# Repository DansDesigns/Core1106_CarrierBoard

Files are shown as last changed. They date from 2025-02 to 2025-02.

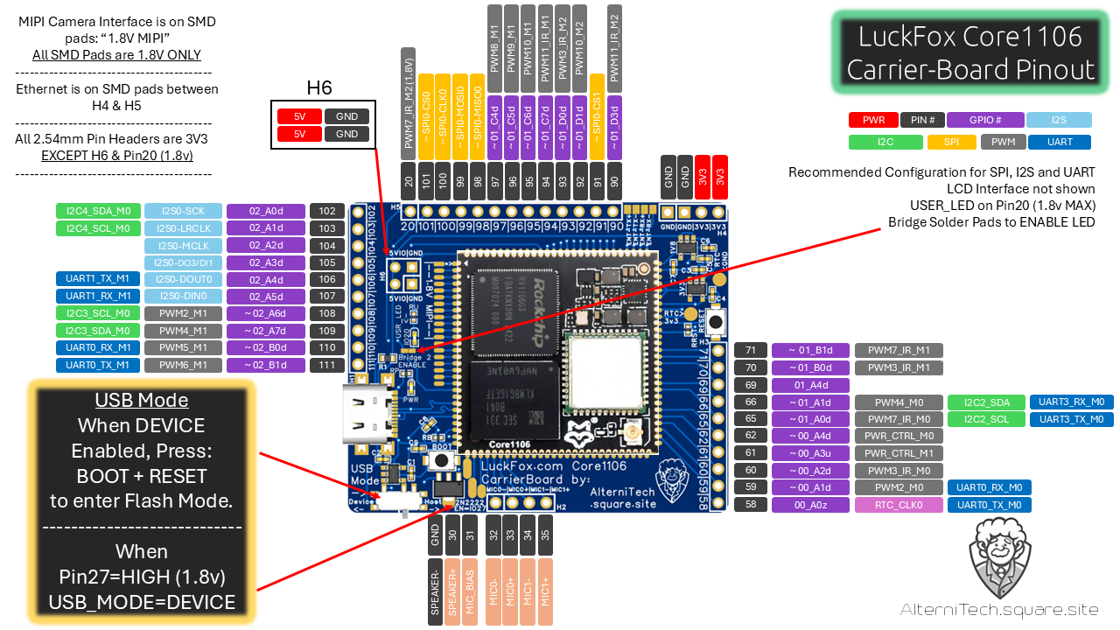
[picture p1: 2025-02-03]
LuckFox_Core1106_EasyRead_Pinout.png

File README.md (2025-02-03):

# Core1106_CarrierBoard
 Carrier Board for LuckFox Core1106 Linux SBC
LuckFox_Core1106_EasyRead_Pinout

## Features:

* All usable GPIO's are connected to 2.54mm Pin Headers (all 3.3v Logic EXCEPT Pin20 (1.8v MAX))
* ALL SMD Pads are 1.8v, EXCEPT for ENET (Ethernet)
* USB-C Programming/USB Host
* USB Mode Switch connects 3.3v & USB_VBUSDET (Enable to enter USB Device Mode, PRESS BOOT + RESET to enter Flash Mode)
* 2N2222 Transistor with ENABLE on Pin27 does same ^^^^^^ (when Pin27 is HIGH (1.8v))
* 5v pins on H6 are directly connected to USB - can be used for In/Out
* 3v3 pins are powered by "3v3" LDO (shared with 3v3SYS) (max 500ma)
* User LED connected to Pin20 (GPIO3_C6d)
	- Connect Solder Pads to ENABLE
*

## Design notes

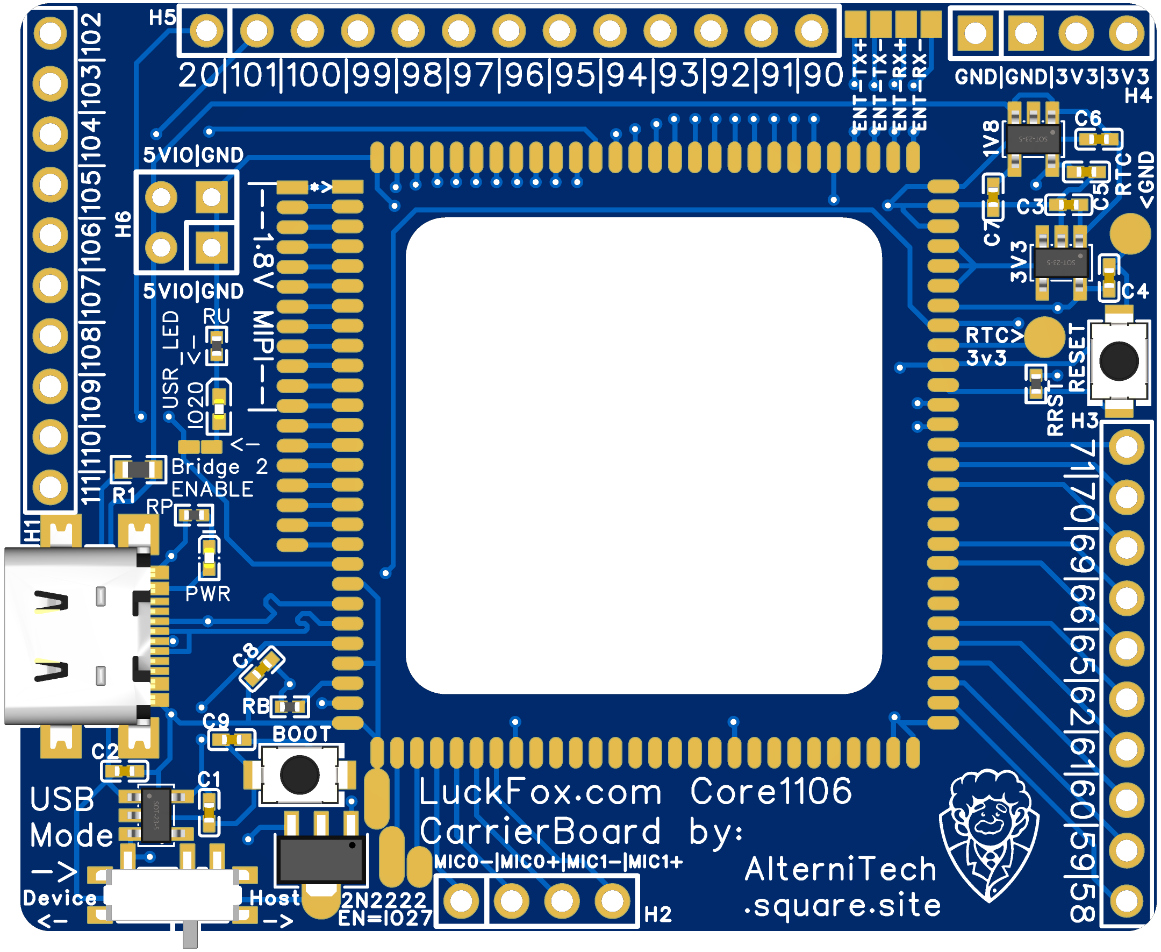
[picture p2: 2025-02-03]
Pictures/Luckfox_Core1106_CarrierBoard(no_headers).png

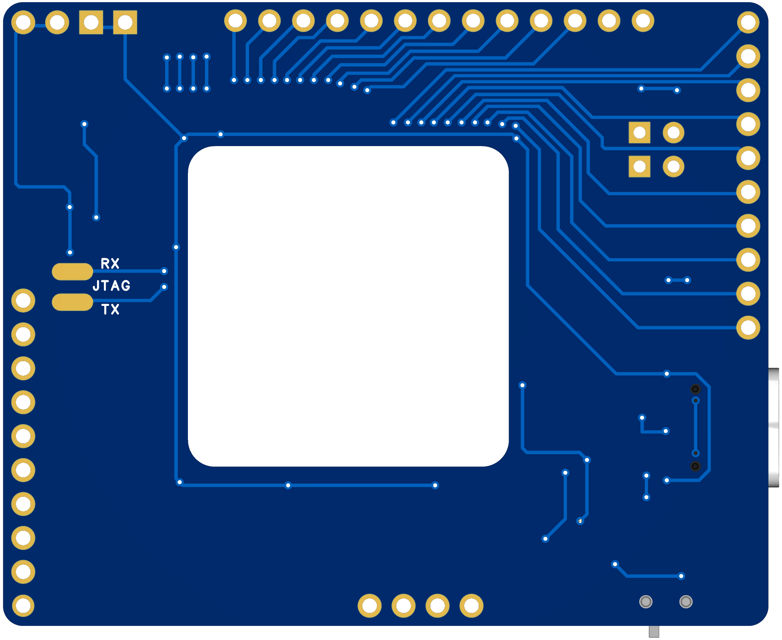
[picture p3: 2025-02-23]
Pictures/Luckfox_Core1106_CarrierBoard(no_headers)_back.png

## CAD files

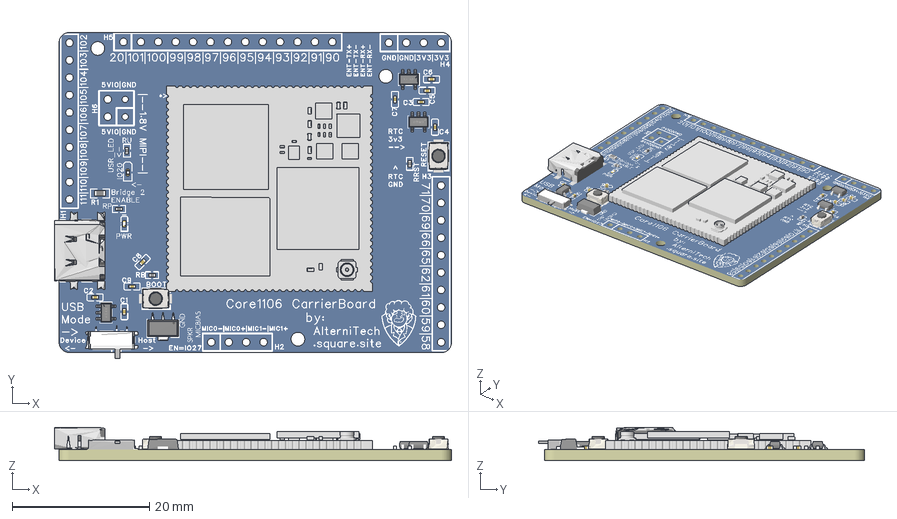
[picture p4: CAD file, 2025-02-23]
3D/3D_Core1106_CarrierBoard_2025-02-10.3mf
57.9 x 47.6 x 4.86 mm

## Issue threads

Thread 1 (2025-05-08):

power supplies

vjoco, 2025-05-08:
I see that core1106 has EA3036C power managment IC to generate 3.3 and 1.8 V... why you added LDOs on the carrier board?

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

vjoco, 2025-05-20:
I populated the board, indeed the module has internal switch type PS, quite efficient. The module over USB operates at 49 mA

DansDesigns, 2025-06-16:
Hi vjoco, sorry for the delay in getting back to you,

Thank you for the clarification on the LDO's, I had designed and ordered the prototype pcbs before i received the Core1106, so was unsure if they were actually included as there were several inconsistencies found in the documentation.

My prototype boards also had an error with the resistor for the BOOT button, gnd goes to the wrong side
and the USR_LED is actually the system activity LED..

other than that i can confirm everything else works.

I have not updated the board as I have struggled to get an SPI 1.5" RGB OLED working with the Core1106 and so reverted my project back to the NanoPi Neo Air

vjoco, 2025-06-16:
Hi.. thanks for the clarifications. The BOOT resistor issue I found it too, but was easy to solve.

One question: in terms of power consumption, how much NanoPi Neo Air consumes?

DansDesigns, 2025-06-17:
haha glad you found that one, i ended up soldering a cable to the BOOT pin in order to connect it to one of the gnd pin-headers.

I have found the NanoPi Neo Air to consume around 600ma with wifi on, with it off its lower at roughly 350-400ma
during boot it can spike to around 800ma for brief moments..
